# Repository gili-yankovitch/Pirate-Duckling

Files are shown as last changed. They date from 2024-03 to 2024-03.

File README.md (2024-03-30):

# Pirate-Duckling
Pirate Duckling is an ATTiny85 based Rubber Ducky clone. It is built with absolute minimal components in mind.

This PCB is manufactured with 1.2mm thickness. As USB ports are thicker than this, additional "USB Fatterners" are provided under hardware/ to add the necessary thickness to the USB part of the PCB.

<p align="center">
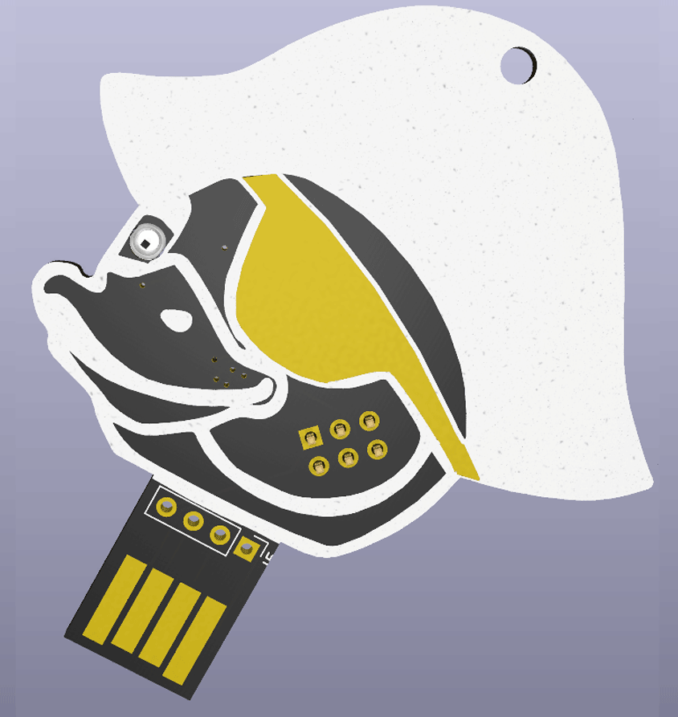
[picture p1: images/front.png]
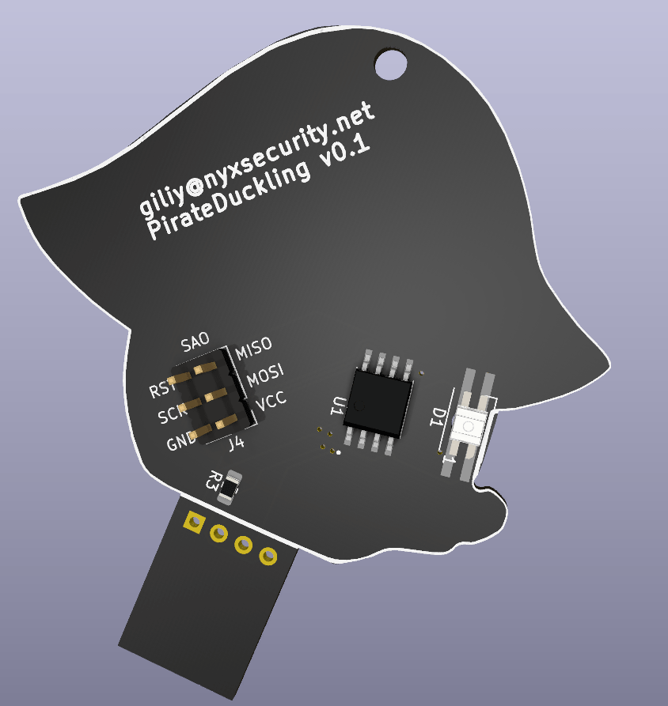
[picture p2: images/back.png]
   
</p>

## Prerequisits
### Software
Please install the following software to be able to flash software to the device:
* [Arduino SDK](https://www.arduino.cc/en/software)
* [Platformio](https://platformio.org/install/cli) or VScode with Platformio AddOn
* [Digispark Drivers](https://github.com/digistump/DigistumpArduino/releases/download/1.6.7/Digistump.Drivers.zip)
* [micronucleus](https://github.com/micronucleus/micronucleus/releases/download/v2.6/micronucleus-cli-master-882e7b4a-x86_64-MINGW64_NT-10.0-17763.zip) in case platformio's toolchain fails to find libusb0.dll, extract it under `%USERPROFILE%\.platformio\packages\tool-micronucleus`

### Hardware
All PCB specs are provided here under hardware/ and this can be easily manufactured as well as paneled for a larger volume. There are no special requirements for this board's manufacturing process.

#### Bill of Materials
| Quantity | Component Description | Mfr. No | Datasheet |
|---|---|---|---|
| 1 | SMD 1 kOhms 125 mW 0805 5% | RC0805JR-071KL | [Datasheet](https://www.mouser.co.il/datasheet/2/447/PYu_RC_Group_51_RoHS_L_11-1984063.pdf) |
| 1 | MCU AVR 8K FLSH 512B EE 512B SRAM ADC 5V | ATTiny85-20SU | [Datasheet](https://www.mouser.co.il/datasheet/2/268/Atmel_2586_AVR_8_bit_Microcontroller_ATtiny25_ATti-1315542.pdf) |
| 1 | 0.2W Intelligent external control surface mount SMD LED | SK6812Mini-E | [Datasheet](https://cdn-shop.adafruit.com/product-files/4960/4960_SK6812MINI-E_REV02_EN.pdf) |

# Software
## Software Building
Building the software is easy using platformio. Simply execute:
```
pio run --environment attiny85
```

### Software Flashing Using Arduino as an ISP using the broken-out pins
The [platformio.ini](platformio.ini) project is currently configured to be flashed using the Digispark bootloader, but it can also be flashed directly using an Arduino as an ISP. Simply connect the Arduino to the broken-out pin headers, uncomment the commented lines under platforio.ini and run:
```
pio run -t fuses
pio run --environment attiny85 --target upload
```

### Software Flashing Using the Digispark bootloader using the USB port
Flashing software using the USB port would require flashing the ATTiny85 with the bootloader [Attiny85.hex](https://github.com/gili-yankovitch/tinypad/blob/main/Digistump/bootloader/ATtiny85.hex) using the flash script [Burn_AT85_bootloader.bat](https://github.com/gili-yankovitch/tinypad/blob/main/Digistump/bootloader/Burn_AT85_bootloader.bat) which also sets the appropriate fuses at flash time.
```
%USERPROFILE%\.platformio\packages\arduino\tools\avrdude\6.3.0-arduino17\bin\avrdude.exe -C"%USERPROFILE%\.platformio\packages\arduino\tools\avrdude\6.3.0-arduino17\etc\avrdude.conf" -v -pattiny85 -cstk500v1 -P<COMPORT> -b19200 -Uflash:w:"ATtiny85.hex":i -U lfuse:w:0xe1:m -U hfuse:w:0xdd:m -U efuse:w:0xfe:m
```
* Don't forget to swap `<COMPORT>` to the appropriate COM port.

After that, you can build the software normally and flash it using the USB port. Run the following command and remember to only plug in the USB once the flash utility indicates it:
```
pio run --environment digispark-tiny --target upload
```

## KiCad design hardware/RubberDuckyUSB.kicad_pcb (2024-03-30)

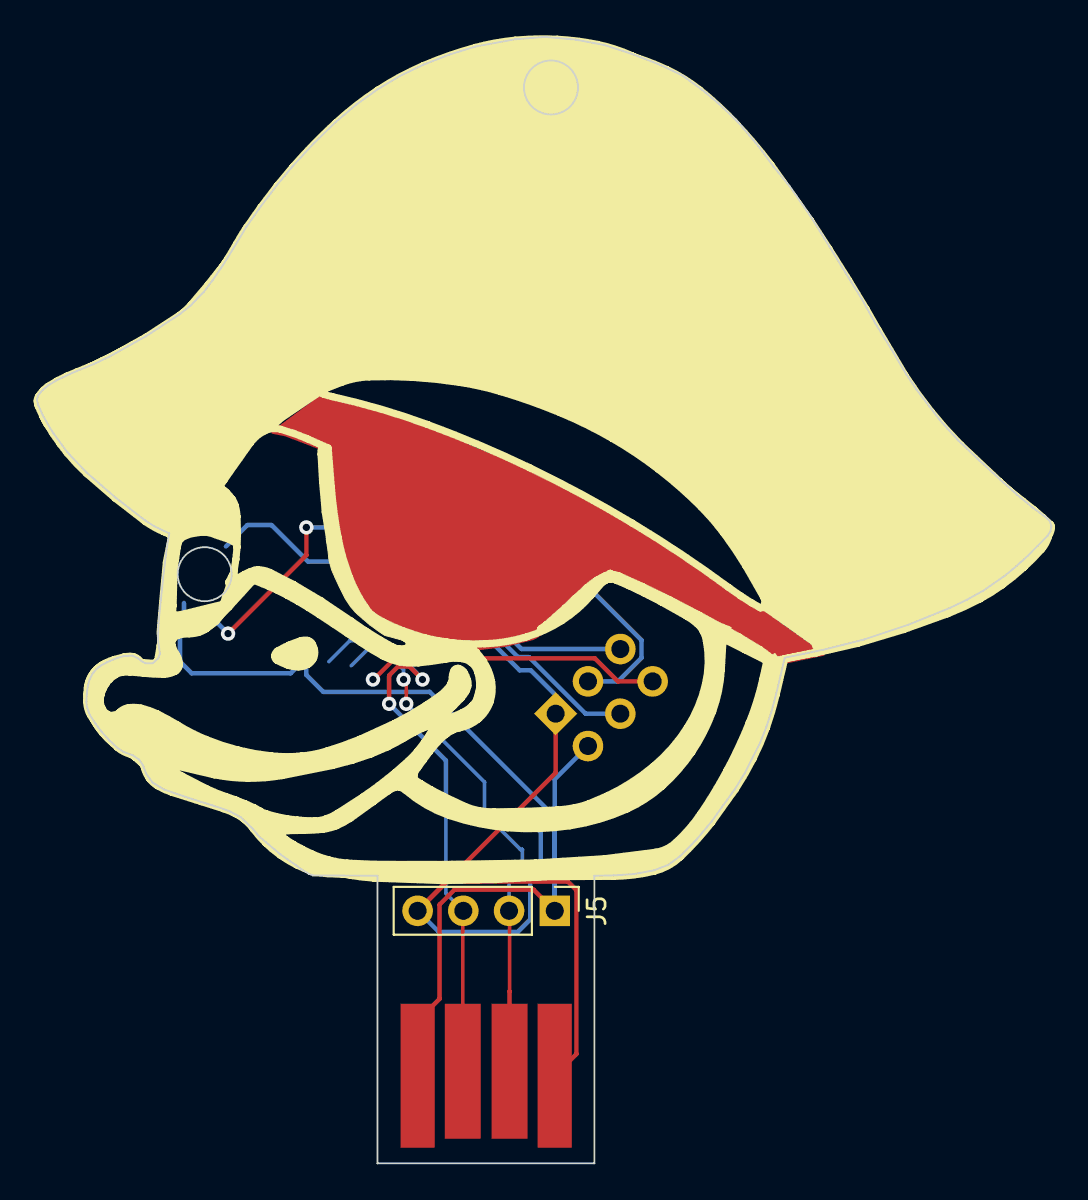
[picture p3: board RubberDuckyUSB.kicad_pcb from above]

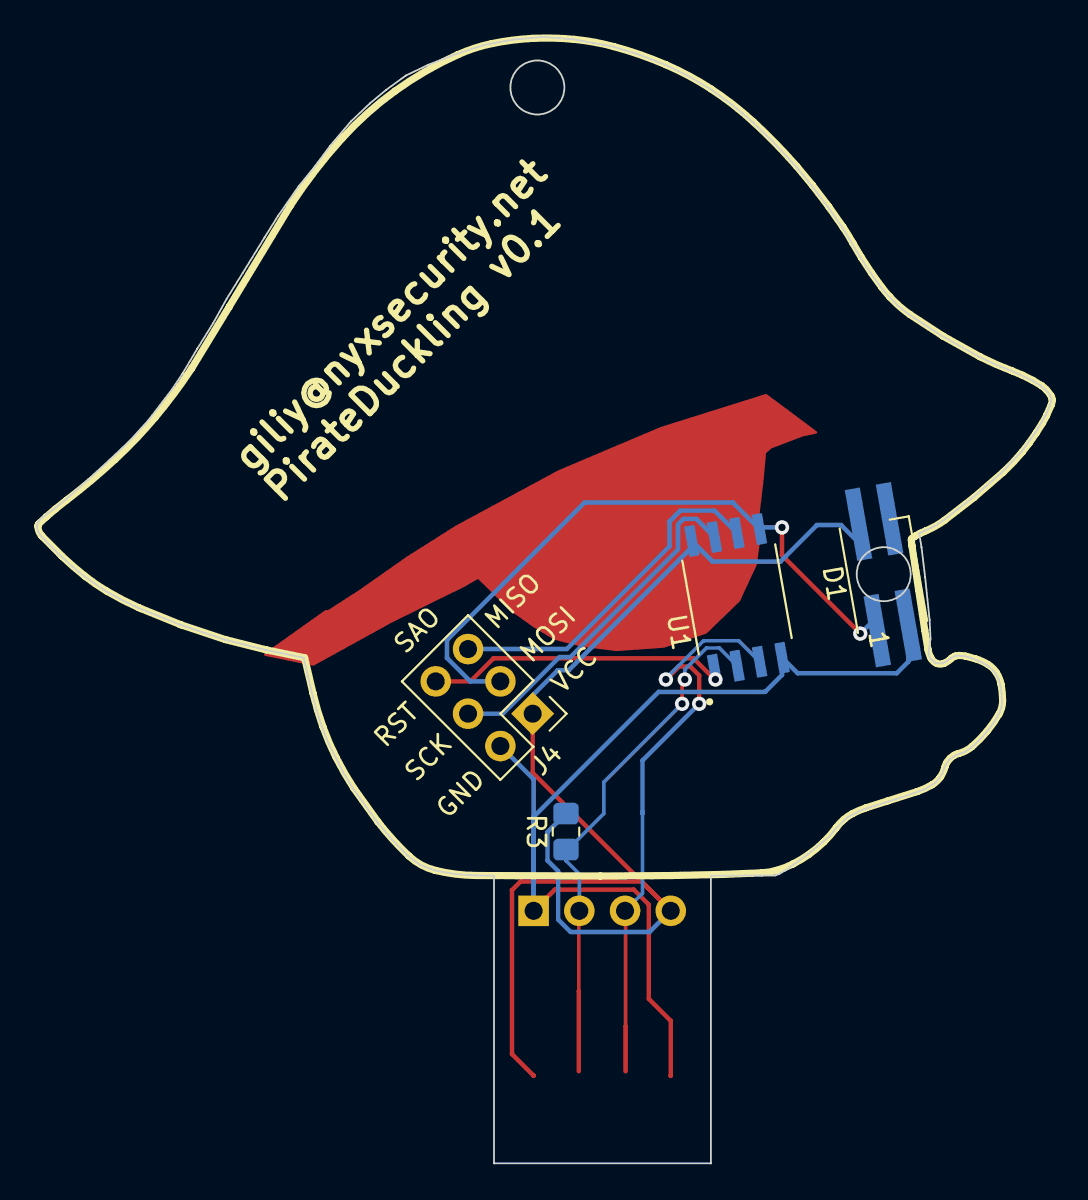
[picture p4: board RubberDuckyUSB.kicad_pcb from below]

Board: 2 copper layers, 56.4 x 62.6 mm, 6 parts (4 on the bottom side), 8 nets.

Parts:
D1: SK6812MINI; LED_SK6812MINI_PLCC4_3.5x3.5mm_P1.75mm
J1: USB_A; usb-PCB
J4: Conn_02x03_Odd_Even; PinHeader_2x03_P2.54mm_Vertical
J5: Conn_01x04_Pin; PinHeader_1x04_P2.54mm_Vertical
R3: R; R_0805_2012Metric_Pad1.20x1.40mm_HandSolder
U1: ATTINY85-20SU; SOIC127P798X216-8N

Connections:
Connector-D+: J1.3 (D+), J5.3, U1.3 (PB4)
Connector-D-: J1.2 (D-), J5.2, R3.1, U1.2 (PB3)
DATA: D1.3 (DIN), J4.3, U1.5 (PB0)
GND: D1.2 (VSS), J1.4 (GND), J4.2, J5.1, U1.4 (GND)
MISO: J4.5, U1.6 (PB1)
RST: J4.6, U1.1 (PB5)
SCK: J4.4, U1.7 (PB2)
Vcc: D1.4 (VDD), J1.1 (VBUS), J4.1, J5.4, R3.2, U1.8 (VCC)

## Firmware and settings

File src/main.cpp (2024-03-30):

/*
  08/01/2016
  Author: Makerbro
  Platforms: ESP8266
  Language: C++
  File: Rainbow.ino
  ------------------------------------------------------------------------
  Description:
  Demo for NeoPixelBus WS2812 LED Library showcasing a rainbow  pattern
  cycle on a WS2812B LED strip controlled by an ESP8266.  Modified from
  strandtest.ino in the Adafruit NeoPixel Library.
  ------------------------------------------------------------------------
  Dependencies:
  NeoPixelBus Library -
  https://github.com/Makuna/NeoPixelBus
  ------------------------------------------------------------------------
  Please consider buying products from ACROBOTIC to help fund future
  Open-Source projects like this! We'll always put our best effort in every
  project, and release all our design files and code for you to use.
  https://acrobotic.com/
  ------------------------------------------------------------------------
  License:
  Released under the MIT license. Please check LICENSE.txt for more
  information.  All text above must be included in any redistribution.
*/

#include <NeoPixelBus.h>
#include "VUSB_Keyboard/VUSB_Keyboard.h"

const uint16_t PixelCount = 1;
const uint8_t PixelPin = PINB0; // Ignored for Esp8266

// three element pixels, in different order and speeds
NeoPixelBus<NeoGrbFeature, Neo800KbpsMethod> strip(PixelCount, PixelPin);

void setup()
{
  // this resets all the neopixels to an off state
  strip.Begin();
  strip.Show();
}

RgbColor color;
uint8_t pos;

RgbColor Wheel(uint8_t WheelPos);

static bool executed = false;

void loop()
{
#if 1
  if (!executed)
  {
    executed = true;
    VUSB_Keyboard.sendKeyStroke(0);
    VUSB_Keyboard.sendKeyStroke(KEY_R, MOD_GUI_LEFT);
    VUSB_Keyboard.delay(200);
    VUSB_Keyboard.printf("chrome https://www.youtube.com/watch?v=dQw4w9WgXcQ&ab_channel=RickAstley");
    VUSB_Keyboard.sendKeyStroke(KEY_ENTER);
  }
#endif
  for (uint16_t j = 0; j < 256 * 5; j++) // complete 5 cycles around the color wheel
  {
    for (uint16_t i = 0; i < PixelCount; i++)
    {
      // generate a value between 0~255 according to the position of the pixel
      // along the strip
      pos = ((i * 256 / PixelCount) + j) & 0xFF;
      // calculate the color for the ith pixel
      color = Wheel(pos);
      // set the color of the ith pixel
      strip.SetPixelColor(i, color);
    }
    strip.Show();
    // strip.Darken(100);
    delay(50);
  }
}

// Input a value 0 to 255 to get a color value.
// The colours are a transition r - g - b - back to r.
RgbColor Wheel(uint8_t WheelPos)
{
  WheelPos = 255 - WheelPos;
  if (WheelPos < 85)
  {
    return RgbColor(255 - WheelPos * 3, 0, WheelPos * 3);
  }
  else if (WheelPos < 170)
  {
    WheelPos -= 85;
    return RgbColor(0, WheelPos * 3, 255 - WheelPos * 3);
  }
  else
  {
    WheelPos -= 170;
    return RgbColor(WheelPos * 3, 255 - WheelPos * 3, 0);
  }

  VUSB_Keyboard.delay(1);
}

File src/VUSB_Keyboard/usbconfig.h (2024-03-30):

/* Name: usbconfig.h
 * Project: V-USB, virtual USB port for Atmel's(r) AVR(r) microcontrollers
 * Author: Christian Starkjohann
 * Creation Date: 2005-04-01
 * Tabsize: 4
 * Copyright: (c) 2005 by OBJECTIVE DEVELOPMENT Software GmbH
 * License: GNU GPL v2 (see License.txt), GNU GPL v3 or proprietary (CommercialLicense.txt)
 * This Revision: $Id: usbconfig-prototype.h 767 2009-08-22 11:39:22Z cs $
 * Modified for Digispark by Digistump
 * further modified for use with Attiny84, 12 MHz crystal clock and D-/D+ at PA1/PA0
 */

#ifndef __usbconfig_h_included__
#define __usbconfig_h_included__

/*
General Description:
This file is an example configuration (with inline documentation) for the USB
driver. It configures V-USB for USB D+ connected to Port D bit 2 (which is
also hardware interrupt 0 on many devices) and USB D- to Port D bit 4. You may
wire the lines to any other port, as long as D+ is also wired to INT0 (or any
other hardware interrupt, as long as it is the highest level interrupt, see
section at the end of this file).
+ To create your own usbconfig.h file, copy this file to your project's
+ firmware source directory) and rename it to "usbconfig.h".
+ Then edit it accordingly.
*/

/* ---------------------------- Hardware Config ---------------------------- */

#if defined(__AVR_ATtiny44__) || defined(__AVR_ATtiny84__)
#define USB_CFG_IOPORTNAME A
#define USB_CFG_DMINUS_BIT 1
#define USB_CFG_DPLUS_BIT 0

#elif defined(__AVR_ATtiny45__) || defined(__AVR_ATtiny85__)
#define USB_CFG_IOPORTNAME B
#define USB_CFG_DMINUS_BIT 3
#define USB_CFG_DPLUS_BIT 4

#elif defined(__AVR_ATtiny87__) || defined(__AVR_ATtiny167__)
#define USB_CFG_IOPORTNAME B
#define USB_CFG_DMINUS_BIT 3
#define USB_CFG_DPLUS_BIT 6

#elif defined(__AVR_ATtiny461__) || defined(__AVR_ATtiny861__)
#define USB_CFG_IOPORTNAME B
#define USB_CFG_DMINUS_BIT 5
#define USB_CFG_DPLUS_BIT 6
#else
/*	ATtiny2313, ATmega8/48/88/168	*/
#define USB_CFG_IOPORTNAME D
#define USB_CFG_DMINUS_BIT 7
#define USB_CFG_DPLUS_BIT 2
#endif
/* This is the bit number in USB_CFG_IOPORT where the USB D+ line is connected.
 * This may be any bit in the port. Please note that D+ must also be connected
 * to interrupt pin INT0! [You can also use other interrupts, see section
 * "Optional MCU Description" below, or you can connect D- to the interrupt, as
 * it is required if you use the USB_COUNT_SOF feature. If you use D- for the
 * interrupt, the USB interrupt will also be triggered at Start-Of-Frame
 * markers every millisecond.]
 */
#define USB_CFG_CLOCK_KHZ (F_CPU / 1000)
/* Clock rate of the AVR in kHz. Legal values are 12000, 12800, 15000, 16000,
 * 16500 and 20000. The 12.8 MHz and 16.5 MHz versions of the code require no
 * crystal, they tolerate +/- 1% deviation from the nominal frequency. All
 * other rates require a precision of 2000 ppm and thus a crystal!
 * Default if not specified: 12 MHz
 */
#define USB_CFG_CHECK_CRC 0
/* Define this to 1 if you want that the driver checks integrity of incoming
 * data packets (CRC checks). CRC checks cost quite a bit of code size and are
 * currently only available for 18 MHz crystal clock. You must choose
 * USB_CFG_CLOCK_KHZ = 18000 if you enable this option.
 */

/* ----------------------- Optional Hardware Config ------------------------ */

// #define USB_CFG_PULLUP_IOPORTNAME   D
/* If you connect the 1.5k pullup resistor from D- to a port pin instead of
 * V+, you can connect and disconnect the device from firmware by calling
 * the macros usbDeviceConnect() and usbDeviceDisconnect() (see usbdrv.h).
 * This constant defines the port on which the pullup resistor is connected.
 */
// #define USB_CFG_PULLUP_BIT          5
/* This constant defines the bit number in USB_CFG_PULLUP_IOPORT (defined
 * above) where the 1.5k pullup resistor is connected. See description
 * above for details.
 */

/* --------------------------- Functional Range ---------------------------- */
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

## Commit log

2024-03-30 Initial commit with sources
    [RubberDuckyUSB.kicad_pcb, RubberDuckyUSB.kicad_sch, USBFatteners.kicad_pcb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]
2024-03-30 Revising hardware files
    [RubberDuckyUSB.kicad_pcb, RubberDuckyUSB.kicad_sch]
2024-03-30 Update README.md with PCB manufacturing thickness details
